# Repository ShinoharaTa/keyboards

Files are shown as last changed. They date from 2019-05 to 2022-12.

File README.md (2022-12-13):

# Shinohara設計キーボード情報

([Click here for the English version of the document.](./LICENSE))

ここには私、Shinoharaの作成したキーボードの情報を記載します。

以下、必要なドキュメント

- [篠原氏の基板設計データ利用規約に関して](./License.md)
- [Amazon 欲しい物リスト](https://www.amazon.co.jp/hz/wishlist/ls/36H4COTLUYA0M?ref_=wl_share)

## BlackMask60 (非売品)

初設計の左右分割 Column Staggardキーボード  
部品点数を削減してシンプルにしつつ耐久性やスイッチ交換可能などのメンテナンス性を確保  
販売はありません。

→後継製品：RURA66

## 素 - Shiro (終売)

2019年の販売開始から2022年まで継続したロングセラー商品
以下でお取り扱いがありました。  



### 販売情報

- [Booth](https://shino3.booth.pm/items/1444895)
- [遊舎工房](https://shop.yushakobo.jp/products/consign_shiro)
- [迷宮商会](https://store.shopping.yahoo.co.jp/meikyuu/gj-kb-201907270001.html)

※現在は終売しました。  
基板のみ販売を継続しています。

### 設計データ

[キーボードの設計データを公開しました。](https://github.com/ShinoharaTa/keyboards/tree/master/Shiro/pcb/Shiro)  
設計データの利用にあたっては、かならず利用規約を読み、同意の上での活用をお願いします。

## 玄 - Kuro

名刺サイズをベースに拡張したキーボード  

- 30%キーボード
- 左右分離式
- 拡張部品で親指対応

## RURA66

BlackMask60ベースに再設計したキーボード

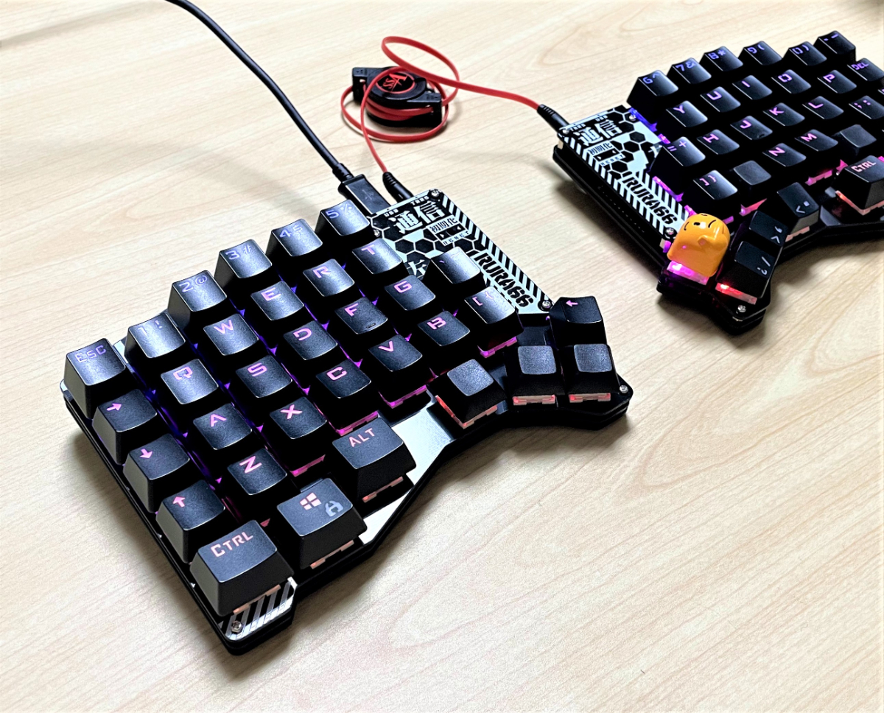
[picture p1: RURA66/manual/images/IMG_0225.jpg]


- 左右分離式
- キーソケットなし
- 価格抑えめ
- Backlight LED（オプション）
- OLED（オプション）

### 販売情報

- [Booth](https://booth.pm/ja/items/2643797)

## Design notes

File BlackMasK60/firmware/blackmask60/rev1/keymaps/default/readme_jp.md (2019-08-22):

# The Default Helix Layout
## 配列

### Qwerty配列

```
 ,-----------------------------------------.             ,-----------------------------------------.
 |   `  |   1  |   2  |   3  |   4  |   5  |             |   6  |   7  |   8  |   9  |   0  | Del  |
 |------+------+------+------+------+------|             |------+------+------+------+------+------|
 | Tab  |   Q  |   W  |   E  |   R  |   T  |             |   Y  |   U  |   I  |   O  |   P  | Bksp |
 |------+------+------+------+------+------|             |------+------+------+------+------+------|
 | Ctrl |   A  |   S  |   D  |   F  |   G  |             |   H  |   J  |   K  |   L  |   ;  |  '   |
 |------+------+------+------+------+------+------+------+------+------+------+------+------+------|
 | Shift|   Z  |   X  |   C  |   V  |   B  |   [  |   ]  |   N  |   M  |   ,  |   .  |   /  |Enter |
 |------+------+------+------+------+------+------+------+------+------+------+------+------+------|
 |Adjust| Esc  | Alt  | GUI  | EISU |Lower |Space |Space |Raise | KANA | Left | Down |  Up  |Right |
 `-------------------------------------------------------------------------------------------------'
```

他の配列(Colemak,Dvorak)は、[readme.md](readme.md) を参照

## コンパイルの仕方

コンパイルは、qmk_firmware のトップディレクトリで行います。

```
$ cd qmk_firmware
```
qmk_firmwareでは各キーボードのコンパイルは、`<キーボード名>:<キーマップ名>`という指定で行います。

```
$ make helix:default
```

キーボードへの書き込みまで同時に行うには下記のように`:avrdude`を付けます。

```
$ make helix:default:avrdude
```

コンパイル結果と中間生成物を消去したい場合は以下のようにします。

```
$ make helix:default:clean
```

## カスタマイズ

Helix キーボードを4行版として製作したり、オプションの OLED をつけたり、
RGB バックライトまたは、RGB Underglow をつけた場合は、
`qmk_firmware/keyboards/helix/rev1/keymaps/default/rules.mk` の以下の部分を編集して機能を有効化してください。

```
# Helix keyboard customize
# you can edit follows 7 Variables
#  jp: 以下の7つの変数を必要に応じて編集します。
HELIX_ROWS = 5              # Helix Rows is 4 or 5
OLED_ENABLE = no            # OLED_ENABLE
LOCAL_GLCDFONT = no         # use each keymaps "helixfont.h" insted of "common/glcdfont.c"
LED_BACK_ENABLE = no        # LED backlight (Enable WS2812 RGB underlight.)
LED_UNDERGLOW_ENABLE = no   # LED underglow (Enable WS2812 RGB underlight.)
LED_ANIMATIONS = yes        # LED animations
IOS_DEVICE_ENABLE = no      # connect to IOS device (iPad,iPhone)

```

## 4行版Helix に対応する

rules.mk の下記の部分を編集して 5 を 4 に変更してください。

```
HELIX_ROWS = 4              # Helix Rows is 4 or 5
```

## RGB バックライトを有効にする

rules.mk の下記の部分を編集して no を yes に変更してください。

```
LED_BACK_ENABLE = yes        # LED backlight (Enable WS2812 RGB underlight.)
```

## RGB Underglow を有効にする

rules.mk の下記の部分を編集して no を yes に変更してください。
```
LED_UNDERGLOW_ENABLE = yes   # LED underglow (Enable WS2812 RGB underlight.)
```

## OLEDを有効にする

rules.mk の下記の部分を編集して no を yes に変更してください。
```
OLED_ENABLE = yes            # OLED_ENABLE
```

## iPad/iPhoneサポートを有効にする。

rules.mk の下記の部分を編集して no を yes に変更してください。
RBG Underglow や RGBバックライトの輝度を抑えて、iPad, iPhone にも接続できるようになります。

```
IOS_DEVICE_ENABLE = no      # connect to IOS device (iPad,iPhone)
```

## リンク

* さらに詳細は、[こちら helix/Doc/firmware_jp.md](https://github.com/MakotoKurauchi/helix/blob/master/Doc/firmware_jp.md)をご覧ください。
* [Helix top](https://github.com/MakotoKurauchi/helix)

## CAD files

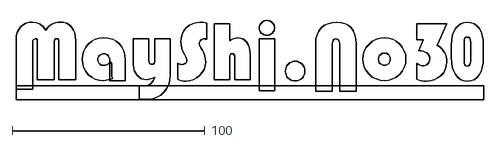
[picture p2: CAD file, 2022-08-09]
Shiro/pcb/Shiro/design/logo_confirm.dxf
242.5 x 41.0

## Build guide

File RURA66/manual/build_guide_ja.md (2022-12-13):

# 左右分割 60% キーボード「RURA66」ビルドガイド

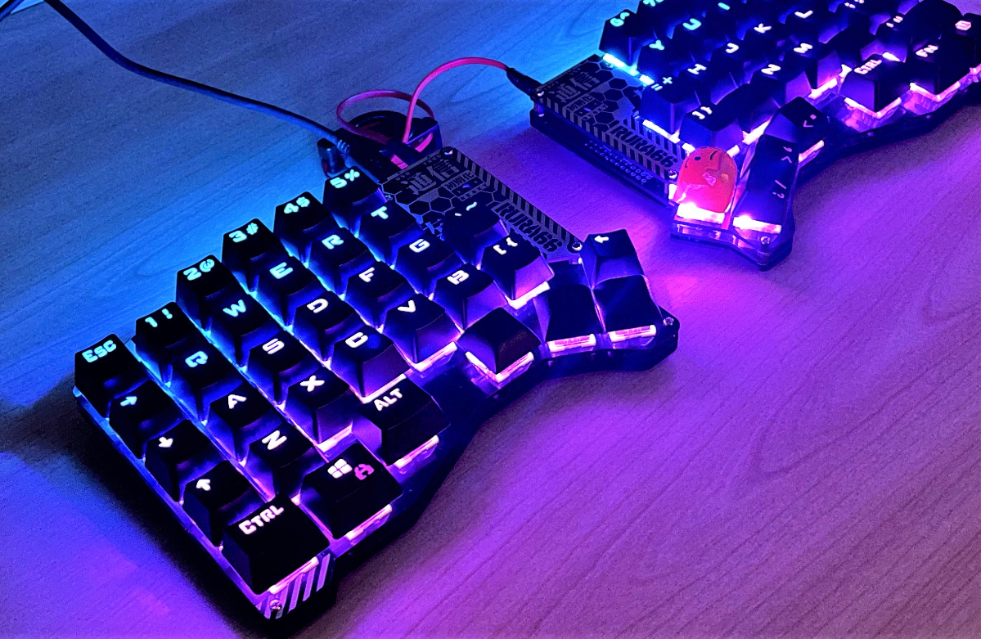
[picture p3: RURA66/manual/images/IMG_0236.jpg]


## はじめに

このキーボードは66キーの左右分割型キーボードです。  
部品点数を削り、最小構成は基本要素のみに限定しているため、左右分割ColumnStaggerdを手軽に試してみたい方も利用できます

## お問合せ先

製品に関しまして、ご不明点や不備、また部品の不足がございましたら、以下フォームよりご連絡ください。
※お問い合わせからお返事まで少々お時間を頂く場合がございます。

https://forms.gle/LfstzLrk8dojknbf6

不足部品に関しましては、当方よりご連絡いただいた住所へ送付させていただきます。

## 部品リスト

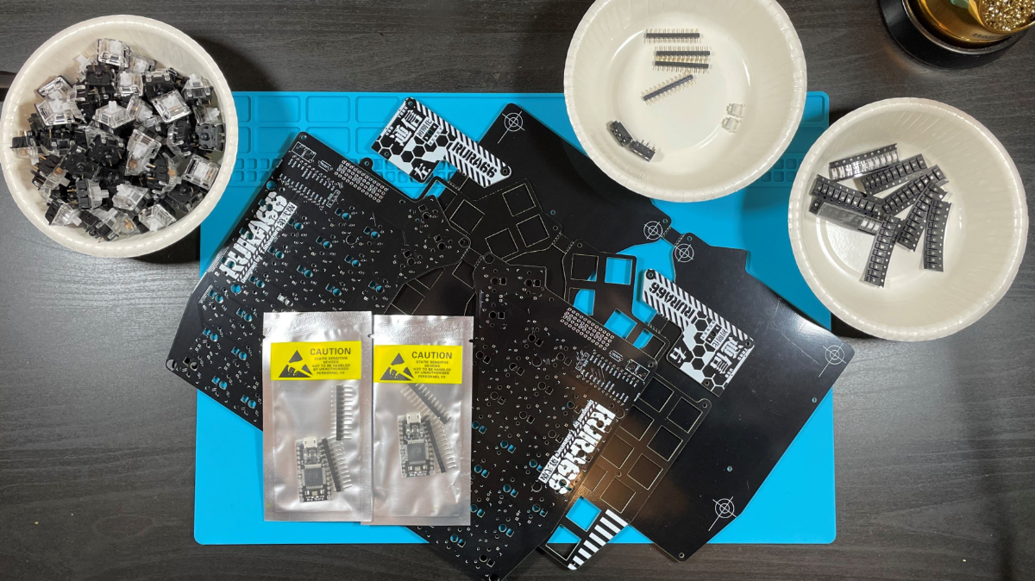
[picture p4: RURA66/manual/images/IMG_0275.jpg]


**キット同梱品**

- PCB x1
- トッププレート x1
- ボトムプレート x1
- チップダイオード x66（予備あり）
- リセットスイッチ x2
- TRRSジャック x2
- ProMicro x2
- コンスルーピンヘッダ x4
- ネジ 4mm x40（予備あり）
- スペーサー 7mm x20（予備あり）

**ご自身で買い揃えていただくもの**
（全て遊舎工房で入手できます）

- Cherry MX スイッチ及び互換スイッチ x66
- キーキャップセット（1uのみ。不足は適宜買い足してください）
- RGB_LED YS-SK6812MINI-E x66（オプション）
- USBケーブル
- TRRSケーブル(3極以上)

## 必要な工具



- ハンダゴテ（温度調節可能なもの推奨）
- ピンセット
- ラジオペンチ
- プラスドライバー（2mm）
- 棒ヤスリ

## 作り方の手順

以下、組み立て手順の図は片手側でおこないます。  
RURA66の基板設計は左右専用設計であるため、実装面に沿って作っていただくことが可能です。

### 基板の分離と加工

まずは基板を点線に沿って切り落とします。  
ラジオペンチで掴んで慎重に追ってください。



点線のバリをヤスリがけして整えます。



お好みで、側面を黒の油性ペンで塗るといい感じになります。

### バックライトLEDの取り付け（オプション）

**※この項目はバックライトLEDをオプションで購入し、光らせたい人むけの情報となります。**

（初期ロットのみ）LEDの枠が小さいため、下記の図のようにヤスリで穴を広げます。  
おすすめは100円ショップ等で取り扱いのある三角/四角のダイヤモンドヤスリを使用します。



以下の図のように、LEDの向きをマークにあわせて配置します。全部、向きは一緒になります。  
はんだ付けのときは、270度似設定してください。長時間コテを当てるとLEDが星になります。

一つだけハンダを乗せたら、再度溶かして素早くピンセットで向きを変えます。



なるべく、一つのLEDに熱が入りすぎないように、複数を並行にはんだ付けしていきます。  
はんだ付け完了後、動作確認のため先にProMicroの取り付けと、ライトの点灯チェックを行ってください



### ダイオードの取り付け

ダイオードのパッドに、片側ずつ予備ハンダをします。

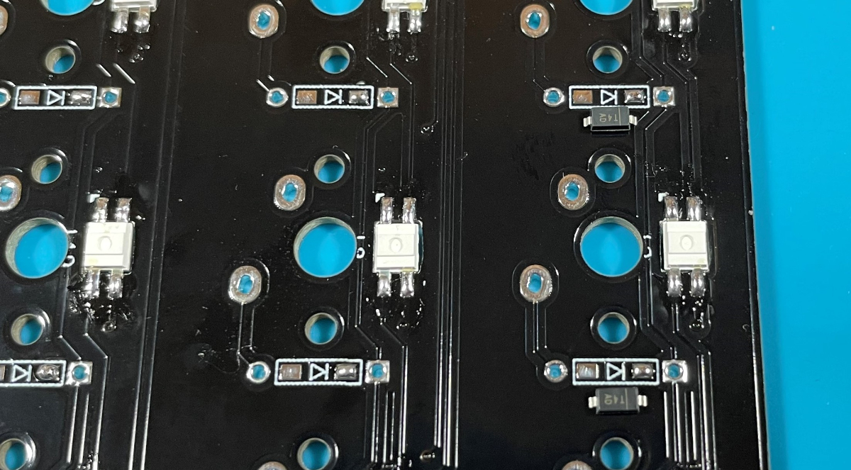
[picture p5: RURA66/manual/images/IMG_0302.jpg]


ダイオードの向きを揃えて、ピンセットではんだ付けしていきます。  
**※極性注意・・・！！**

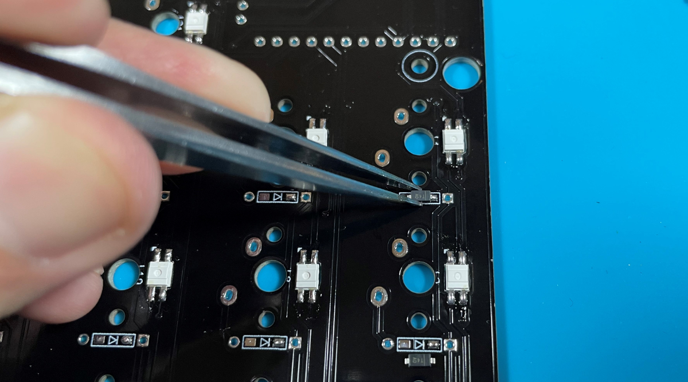
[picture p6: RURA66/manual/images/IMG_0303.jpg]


全部で33個、同じ向きに配置します。

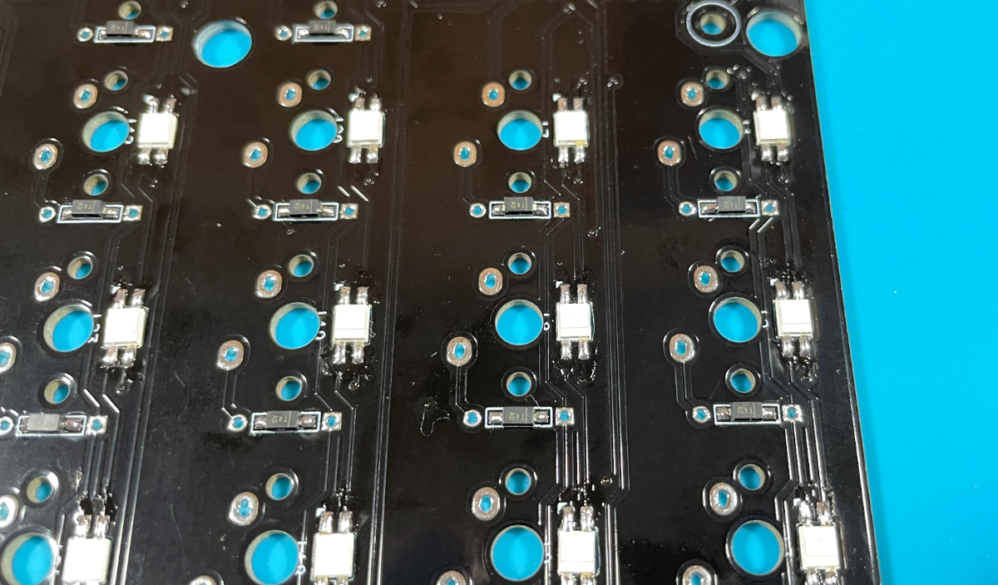
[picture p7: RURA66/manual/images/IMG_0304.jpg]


### TRRSジャックとリセットスイッチの取り付け

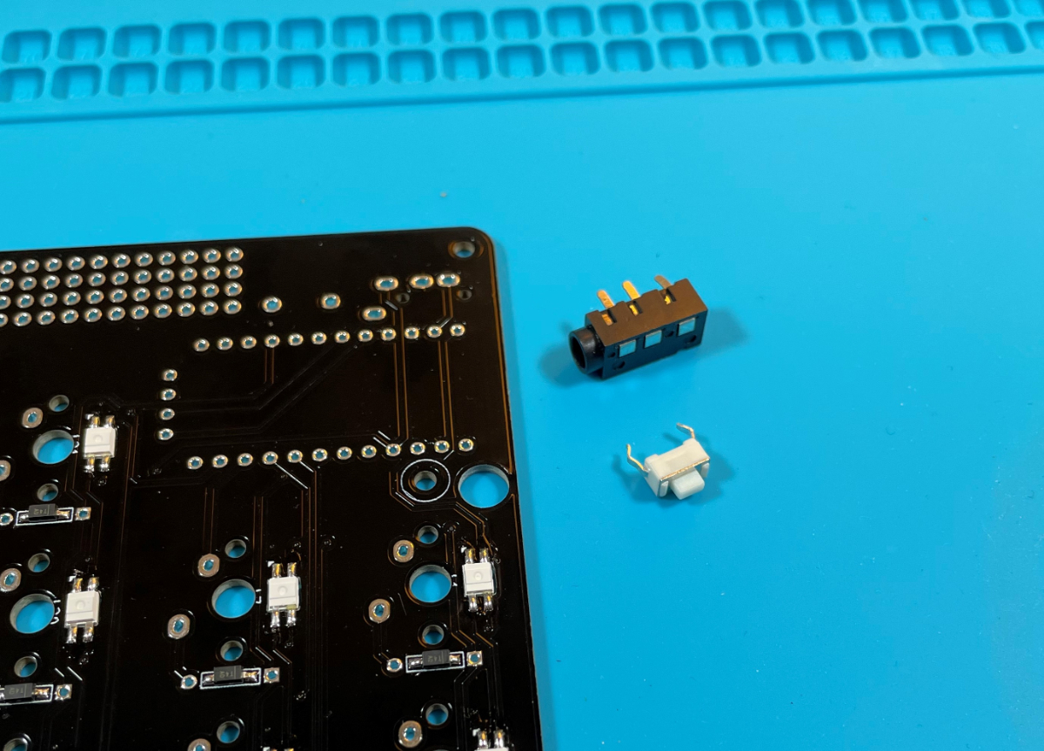
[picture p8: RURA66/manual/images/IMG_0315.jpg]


TRRSジャックから先に取り付けを行います。  
どちらも同じ面から入れ、裏からはんだ付けします。

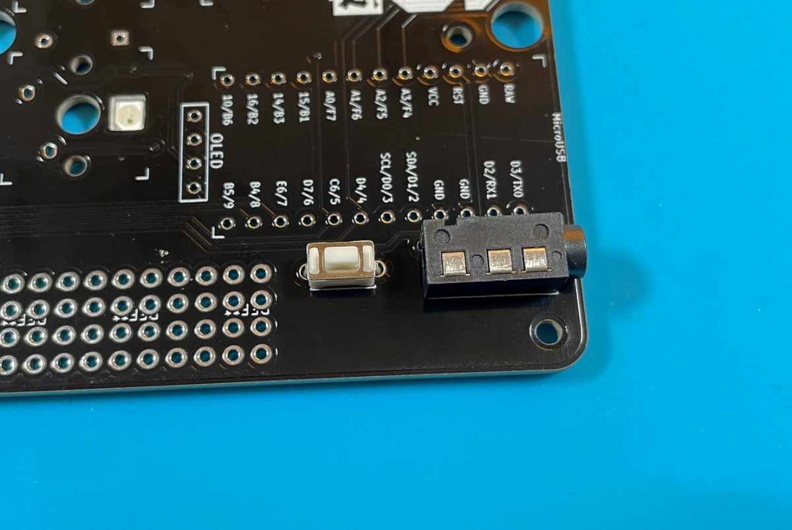
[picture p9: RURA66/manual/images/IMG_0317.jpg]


### スイッチの取り付け

※初期ロットはGateron等の5ピンに対応しておりません。  
5ピンのスイッチを使用する場合は、足を切る必要があります。

メカニカルスイッチをはんだ付けしていきます。  
まずは、トッププレートにスイッチをはめていきます。

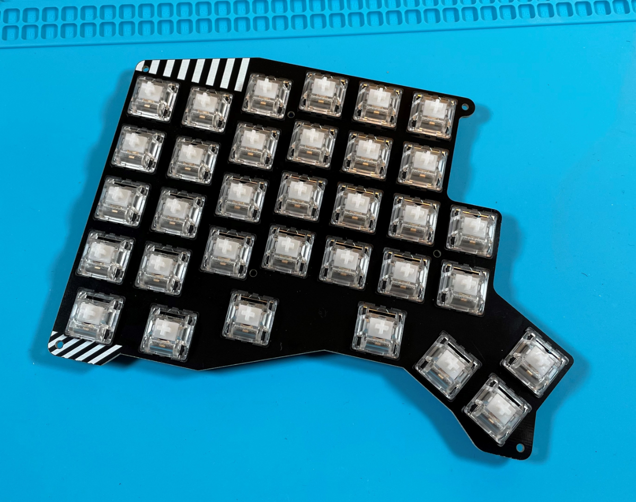
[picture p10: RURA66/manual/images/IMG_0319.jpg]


33個はめます。向きはおなじ方向にまとめてください。  
ピンが折れ曲がっている場合は、手でまっすぐに伸ばしてください。

浮かないように、まず対角をはんだ付けします。  
その後、全体的に浮かないように一つずつ確認しながらはんだ付けをしていきます。

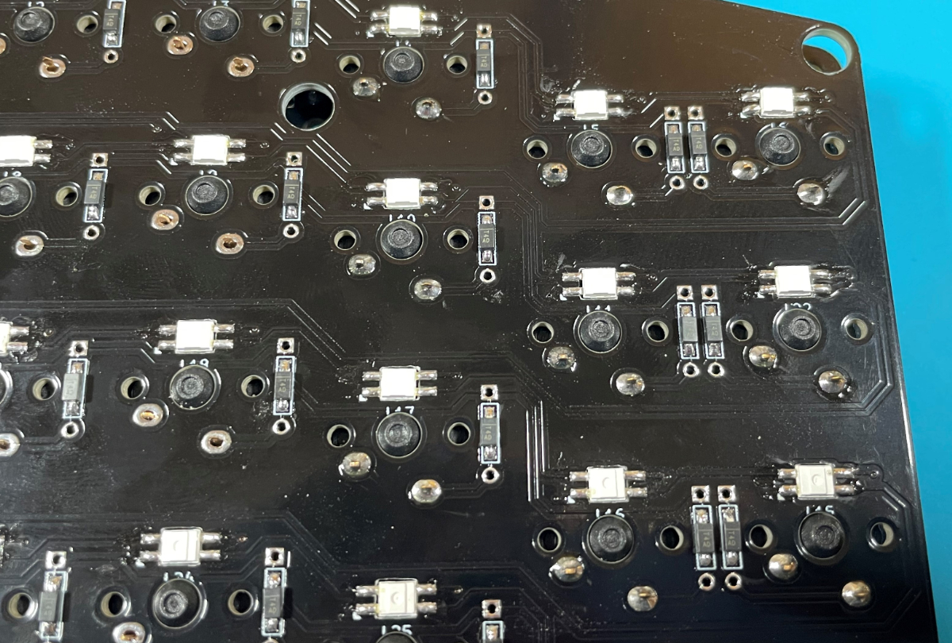
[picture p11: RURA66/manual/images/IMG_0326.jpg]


### ProMicroの取り付け

付属のピンヘッダは使いません。コンスルーピンヘッダを使用します。

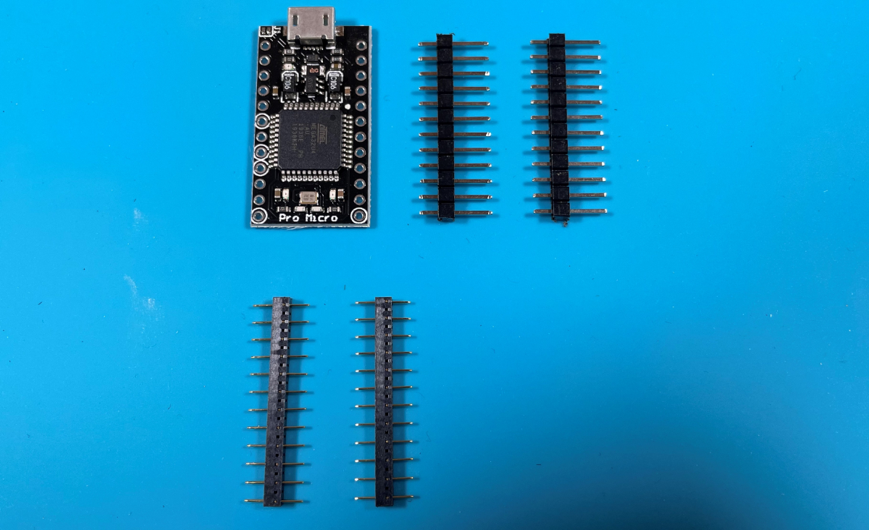
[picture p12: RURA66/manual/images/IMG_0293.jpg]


向きを揃えてコンスルーピンヘッダを指します。

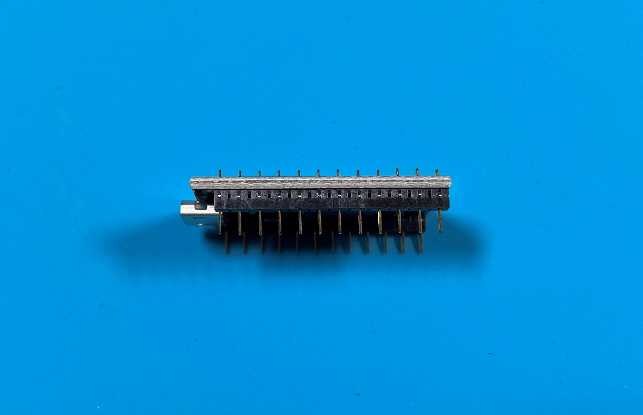
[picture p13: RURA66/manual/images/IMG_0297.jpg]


ProMicroを載せます。

その後、以下の写真のProMicro側のみ（写真の面のみ）をはんだ付けします。

※メインPCB側は、はんだ付け不要です。

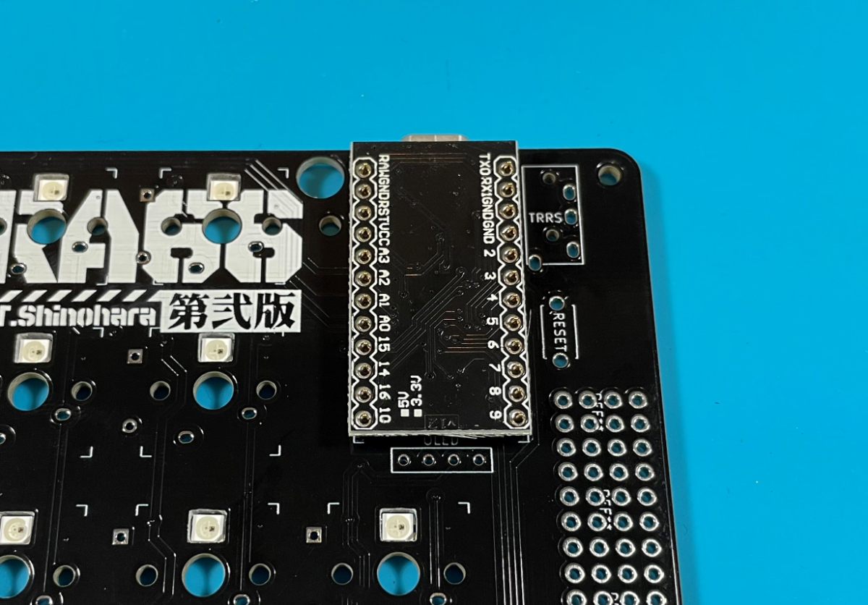
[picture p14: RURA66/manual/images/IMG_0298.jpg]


### ボトムプレート、カバープレートの固定

あまり力を入れすぎずに、ラジオペンチとドライバーを使用して固定してください。  
トッププレート、ボトムプレートをスペーサーと連結し、ネジで留めていきます。

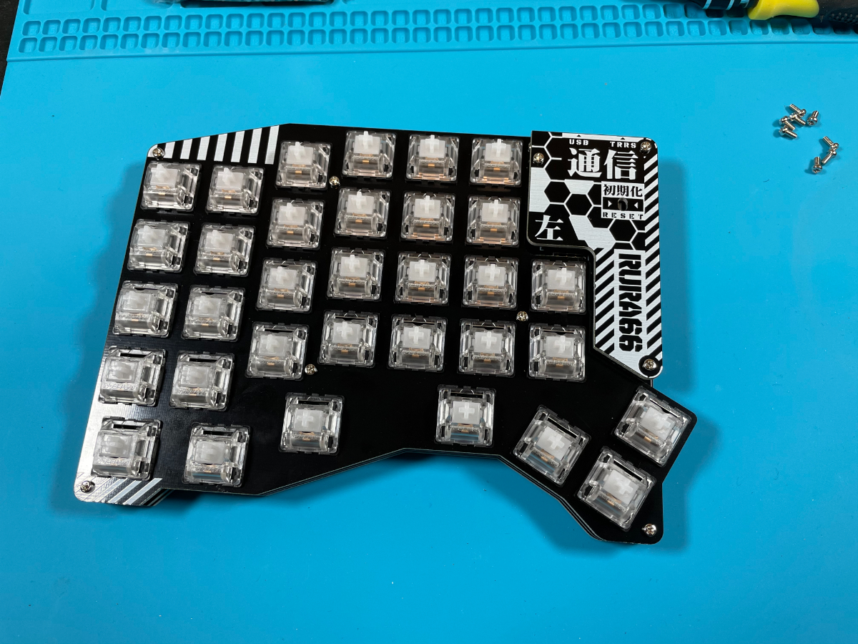
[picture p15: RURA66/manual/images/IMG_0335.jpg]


### 完成に向けて

ゴム足を4隅につけます。  
お好みのキーキャップを取り付けて完成です。



## QMK Firmwareの書き込み

このキーボードは[QMK firmware](https://github.com/qmk/qmk_firmware/)に対応します。  
書き込み手順はQMK Firmwareの使用手順・書き込み手順は公式のドキュメントを参考にしてください

QMKコマンドの使用

```
qmk flash -kb rura66 -km default
```

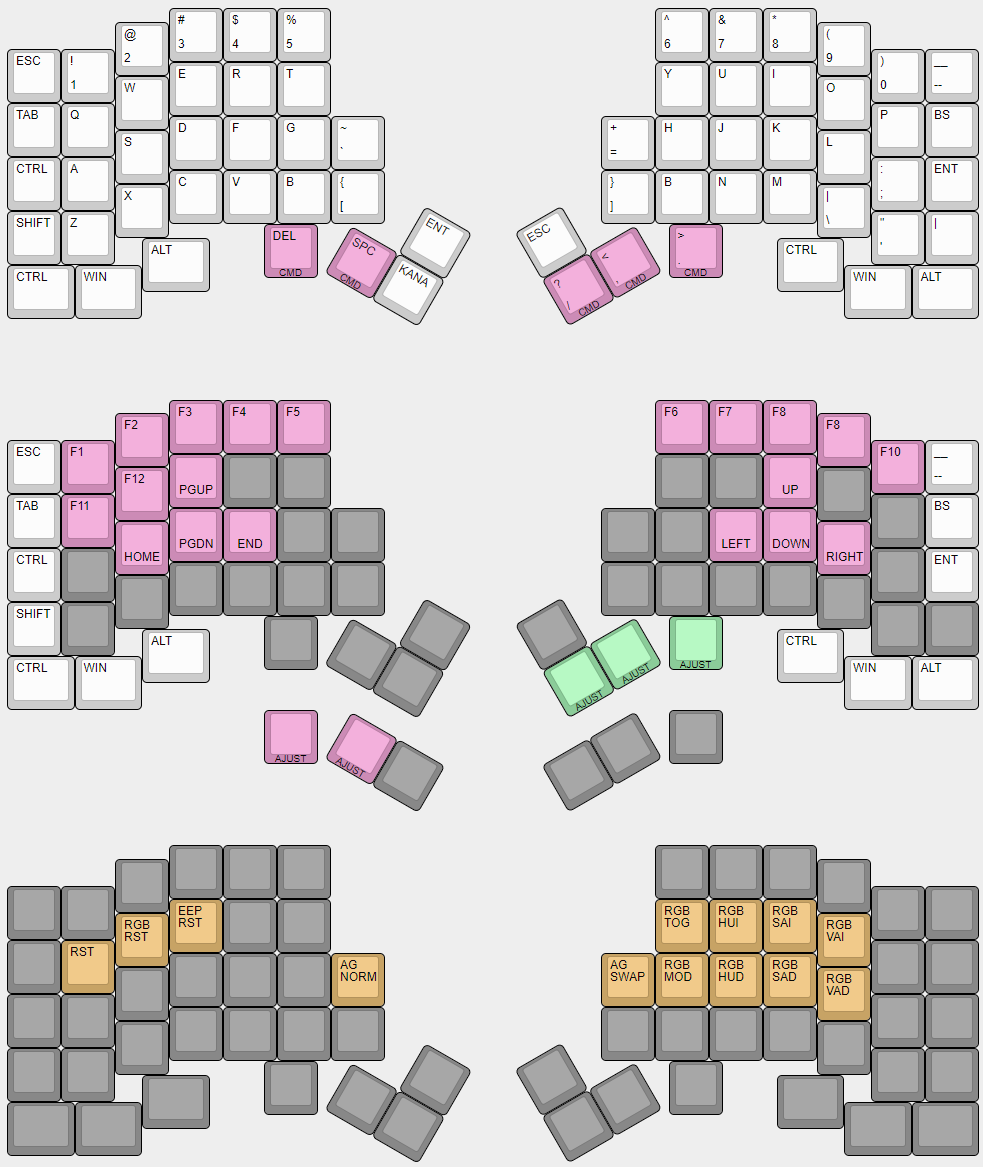
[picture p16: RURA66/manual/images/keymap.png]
keymap


キーマップの変更については`keyboards/rura66/keymap/default`をコピーして、お好きなフォルダ名で保存し、変更を行います。

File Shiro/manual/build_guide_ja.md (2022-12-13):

# マクロキーボード「素 - Shiro」ビルドガイド

2022/8/1より、素-Shiro はオープンソースPCBになりました。

素 - Shiro オープンソースPCBの説明は[こちら](./build_guide_open_source_pcb_ja.md)

素 - Shiro Classicのビルドガイドは[こちら](./build_guide_classic_ja.md)

## はじめに



このキーボードは15キーの縦型キーパッドです。

部品点数を削ったので組み立て難易度は比較的カンタンになっています。

## お問合せ先

製品に関しまして、ご不明点や不備、また部品の不足がございましたら、以下フォームよりご連絡ください。
※お問い合わせからお返事まで少々お時間を頂く場合がございます。

https://forms.gle/LfstzLrk8dojknbf6

不足部品に関しましては、当方よりご連絡いただいた住所へ送付させていただきます。

## 部品リスト

**キット同梱品**



- PCB x1
- トッププレート x1
- ボトムプレート x1
- チップダイオード x15
- リセットスイッチ x1
- ネジ 3mm x6
- ネジ 5mm x4
- スペーサー 5mm x6

**ご自身で買い揃えていただくもの**
（全て遊舎工房で入手できます）



- ProMicro（コンスルーピンヘッダ同梱品）
- Kailh Choc（ロープロスイッチ）x15
- ロープロ対応キーキャップ x15

## 作り方の手順

私が組んだときの手順になりますが、この手順に沿って行えば一応ミスなく組めています。
部品の破損や取付ミスを防ぐためにも、手順は一つ一つ確認しながら進めてください。

### ダイオードの取り付け

ダイオードのパッドに、片側ずつ予備ハンダをします。



ダイオードの向きを揃えて、ピンセットではんだ付けしていきます。
※極性注意・・・！！



全部で15個、同じ向きに配置します。

### リセットスイッチの取り付け

リセットスイッチはこの面から差し込みます



はんだ付けは、こっちの面からおこないます。



### スイッチの取り付け

いよいよメカニカルスイッチをはんだ付けしていきます。
まずは、トッププレートにスイッチをはめていきます。



とりあえず、13個はめます。
折れ曲がっている場合は、手でまっすぐに伸ばしてください。



13箇所入っていることを確認します



浮かないように、まず対角をはんだ付けします。
その後、全体的に浮かないように一つずつ確認しながらはんだ付けをしていきます。

トッププレートに固定されていないスイッチ2個については、そのまま穴に差し込み、同様にはんだ付けします。  
この際、固定の角度のズレ、曲がりにご注意ください。



### ProMicroの取り付け

付属のピンヘッダは使いません。コンスルーピンヘッダを使用します。



向きを揃えてコンスルーピンヘッダを指します。



ProMicroを載せます。

向きは、実装面がオモテに来るように載せてください。  
その後、以下の写真の様にProMicro側のみ（写真の面のみ）をはんだ付けします。

※ShiroのメインPCB側は、はんだ付け不要です。



### カバーの取り付け

カバーをネジ止めしていきます。
短い方のネジ6本、スペーサー6本、ボトムプレートを用意してください。



上記のように、6箇所をネジ止めします。



トッププレートとドッキングします。
4箇所をあわせて、長い方のネジでとめます。



### 完成に向けて

ゴム足を4隅につけます。





お好みのキーキャップを取り付けて完成です。





## QMK Firmwareの書き込み

このキーボードは[QMK firmware](https://github.com/qmk/qmk_firmware/)に対応します。  
書き込み手順はQMK Firmwareの使用手順・書き込み手順は公式のドキュメントを参考にしてください

QMKコマンドの使用

```
qmk flash -kb shiro -km default
```

keymap

キーマップの変更については`keyboards/shiro/keymap/default`をコピーして、お好きなフォルダ名で保存し、変更を行います。

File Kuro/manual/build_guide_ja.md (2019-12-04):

# 分割キーボードキット「玄 - Kuro」ビルドガイド

## はじめに

メイン画像

このキーボードは片側17キー、両手最大34キーの左右分割キーボードです。

組み立てには一部部品の加工、配線などを含みます。また、LEDの実装や、基盤のバリ落としなどが必要となります。

**※注意事項**

- 先行販売分は、ProMicroを使用するスルーホールが一部埋まっています。ピンセットなどで塗膜を落としてください。
- この記事はまだ執筆中です。ご自身が過去にキーボード組み立てた経験をもとに制作してください。
- この記事は深夜４時に書いています。説明用画像が全然足りていません。

## 部品リスト

**キット同梱品**

※画像

- PCB x2
- ボトムプレート x2
- 拡張プレート x2
- チップダイオード x30
- リセットスイッチ x2
- TRRSジャック x2
- ネジ 3mm x20
- ネジ 5mm x8
- スペーサー 5mm x16
- 配線 x6 (3色 2本ずつ）
- 絶縁テープ

**ご自身で買い揃えていただくもの**
(全て遊舎工房で入手できます)

- ProMicro（コンスルーピンヘッダ同梱品）x2
- Kailh Choc(ロープロスイッチ) x34
- ロープロ対応キーキャップ x34
- SK6812MINI LED x30

## 作り方の手順

私が組んだときの手順になりますが、この手順に沿って行えば一応ミスなく組めています。
部品の破損や取付ミスを防ぐためにも、手順は一つ一つ確認しながら進めてください。

作例は左手用です。拡張プレートの取付までは、左右による差異はありません。

### ダイオードの取り付け

ダイオードのパッドに、片側ずつ予備ハンダをします。

※画像

ダイオードの向きを揃えて、ピンセットではんだ付けしていきます。
※極性注意・・・！！

※画像

全部で15個、同じ向きに配置します。

### LEDのはんだ付け（オプション）

この項目はLEDを実装する場合の手順です。無くても構いません。

**LEDは熱に弱いので、ハンダゴテの温度は下げてください。**

※記事を書く。画像いれる。

### リセットスイッチの取り付け

リセットスイッチはこの面から差し込みます

※画像

はんだ付けは、こっちの部品面からおこないます。

※画像

ここでLEDの動作確認を一度行うことをおすすめします。
先に、ProMicroの準備と、QMKファームウェアを書き込みます。

### TRRSジャックの取り付け

TRRSを取り付けます。

※画像

反対面のスイッチと干渉するので、足を短く切ります。（短すぎないように注意）

※画像

ハンダが表面に盛られない程度にはんだ付けします。

※画像

### スイッチの取り付け

いよいよメカニカルスイッチをはんだ付けしていきます。
スイッチの足が折れ曲がっている場合は、手でまっすぐに伸ばしてください。

以下の丸で示した位置は加工が必要です。

ProMicroと重なる位置、一番外側の足は、スイッチと同じ高さになるよう調整してください。

TRRSジャックと重なる位置、プラスチックの足を基板の高さまで切り落としてください。

### ProMicroの取り付け

付属のピンヘッダは使いません。コンスルーピンヘッダを使用します。

![] (https://cdn.discordapp.com/attachments/536423734144401422/597460617997189120/20190707_032439.jpg)

向きを揃えてコンスルーピンヘッダを指します。



ボトムプレート付属の、絶縁テープをUSB部分に張ります。

※画像

ProMicroを載せます。
その後、以下の写真の様にProMicro側のみ（写真の面のみ）をはんだ付けします。
**メインPCB側は、はんだ付け不要です。**

※画像

### 拡張プレート側の加工

へし折ります。

削ります。（ヤスリがあると良し。）

スイッチをはんだ付けします。
**向き注意！！**

### 配線

線の長さをある程度揃えます。キットにより長さは異なります。

※画像

2mmほど被覆をはがし、呼びハンダします。

※画像

基板側にも呼びハンダし、１～３まで、順にはんだ付けします。

※画像

拡張プレート側も同様にはんだ付けします。

※画像

### カバーのネジ止め取り付け

ボトムプレート側から固定していきます。

基板を２枚挟むときは5mmのネジを使用します。
それ以外の箇所は4mmのネジを使います。

※画像

拡張基板側に4mmのネジとスペーサーを固定します。

※画像

メインPCBと4mmのネジで止めます。画像の４箇所です。

※画像

拡張基板の位置決めをして、固定します。

※画像

なお、拡張基板は一番寝かせた状態のとき、はみ出る部分は折って使うことが可能です。

※画像

### 完成に向けて

ゴム足を4隅につけます。

※画像

お好みのキーキャップを取り付けて完成です。

※画像

## QMK Firmwareの書き込み

※後日、公開します。

下記ページよりQMKファームウェアをダウンロードします。

https://github.com/ShinoharaTa/qmk_firmware/tree/kuro

右上、"Clone or download"ボタンより。

そしてダウンロードしたZIPファイルはお好きなところで展開します。
フォルダ階層はなるべく浅いほうがいいです。

gitに慣れている方はクローンしていただいても構いません。

環境構築については、こちら[Helixのビルドマニュアル](https://github.com/MakotoKurauchi/helix/blob/master/Doc/firmware_jp.md)が詳しく解説されています。

**ビルドと書き込み**

```
make kuro:defualt:avrdude
```

これを実行すると本番用のキーマップを書き込めます。
デフォルトでは以下のようになっています。

※キーマップ画像

キーマップの変更については`keyboards/kuro/rev2/keymap/default`をコピーして、お好きなフォルダ名で保存し、変更を行います。

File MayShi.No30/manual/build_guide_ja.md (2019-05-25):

# MayShi.No30 ビルドガイド

## はじめに

このキーボードはmeishi展に出品したキーボードで、基板のサイズは91mm x 55mmのキーボードになります。
左右のスプリットに対応し、ケースで縦方向に拡張すると、最大34キーのキーボードになります。



## 部品リスト

**キット同梱品**

- PCB x1
- トッププレート x1
- ボトムプレート x1

**ご自身で買い揃えていただくもの**
(全て遊舎工房で入手できます)

- ProMicro
- コンスルーピンヘッダ x2
- 面実装ダイオード x15
- Kailh Choc(ロープロスイッチ) x15
- ロープロ対応キーキャップ x15
- LED
- タクトスイッチ
- 3.5mm ステレオケーブル（4極を推奨しています）
- ネジ(5mm, 4mm)
- スペーサー(3mm)x6

## 作り方の手順

1. 瞑想をして集中力を高めます。
1. 基板を片手に組み立てている自分の姿を妄想します。
1. 部屋の片付け、掃除をして雑念を排除します
1. LEDの穴が小さいです。100円ショップに売っているダイヤモンドヤスリで0.2mm〜0.5mmぐらいガリガリ削ります
1. LEDを実装します。
1. ダイオードを実装します。
1. 目が疲れてくるので、休憩をはさみます。
1. TRRSジャックはそのまま入りません。位置合わせのピンを落とします。
1. TRRSジャックがLEDのはんだと干渉します。当たるところをヤスリで落とします。
1. TRRSジャックをはんだ付け前に、PCBの高さで足を切ります。
1. TRRSジャックをはんだ付けします。
1. タクトスイッチをはんだ付けします。
1. ProMicroはいつものように準備します。
1. キースイッチをアクリルにはめていきます。
1. キースイッチをはんだ付けします。ProMicroの真下のは、スイッチの位置決めのピン足がUSBと干渉するので切り落とします。
1. 喉が渇く時間になるのでコカ・コーラを飲みます。
1. LEDは配線不良で途中からつきません。そのうち写真上げます。
1. ケースとカバーをネジどめして組み立てます。ProMicroのとこのネジは応力がかかって破損を防ぐためのもの。ボトムプレートのみに止めます

## Firmware を焼く

QMK Firmwareで、とりあえずHelixのやつ焼けば動きます。
動くものは、出次第自分のTwitterで告知します。もう少々お待ちください。

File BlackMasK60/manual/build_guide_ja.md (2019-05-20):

# BlackMasK60ビルドガイド

## はじめに

このキーボードはキー数がおおよそ60％のキーボードとなります。
キー数は最大70個まで対応で、最小では58個ぐらいになります。

## 部品リスト

**キット同梱品**

- PCB x2
- トッププレート x2
- ボトムプレート x2
- タクトスイッチ x2
- スペーサー 7mm x18
- ネジ 4mm x36
- TRRSジャック x2
- タクトスイッチ x2

**ご自身で買い揃えていただくもの**
(全て遊舎工房で入手できます)

- ProMicro x2
- コンスルーピンヘッダ x4
- キースイッチ（Cherry MX互換） x70
- キーキャップ（Cherry MX互換） x70
- ソケット（Cherry MX用） x70  
とりあえず動くのは70個です。配列を自由に変える場合は90個が理想です。
- ダイオード（SMDも可） x70
- 3.5mm ステレオケーブル（4極を推奨しています）

## 作り方の手順

必ずこの手順に従って組み立てを進めてください。
また、はんだ付けに自身のない方はリード部品が多めのCherry MX互換のものを選択されることを推奨します。

### ダイオードの実装

リードダイオードのはんだ付け
SMDダイオードのはんだ付け

基盤の向き、実装方向
文章は以前のQiita参考

### ソケットの実装

### TRRSジャックの実装

### ProMicroの取り付け

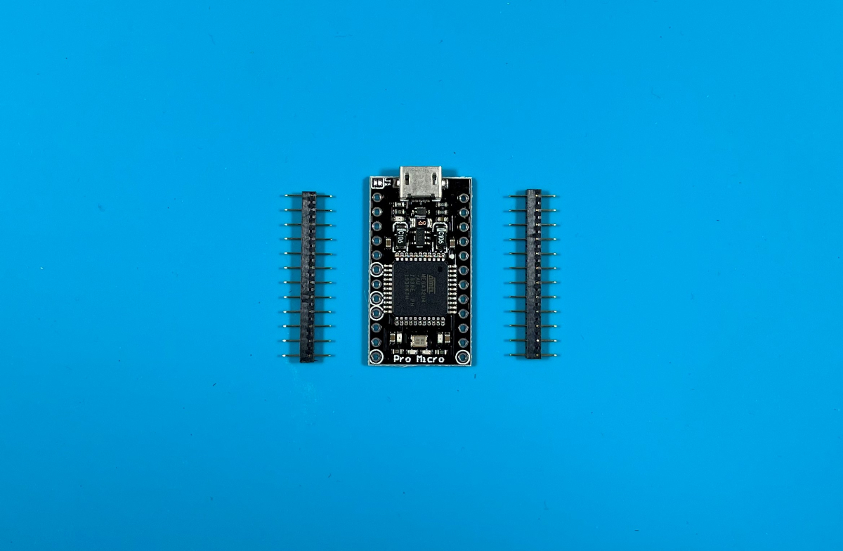
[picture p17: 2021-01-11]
RURA66/manual/images/IMG_0294.jpg

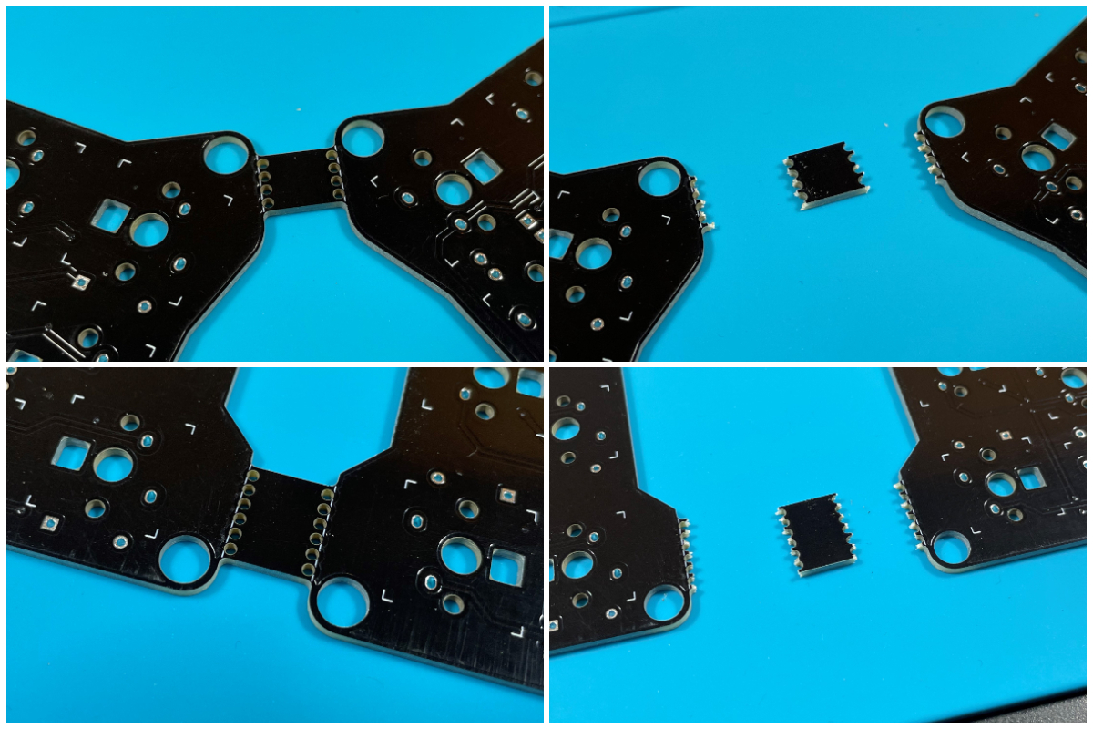
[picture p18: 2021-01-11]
RURA66/manual/images/FotoJet.jpg

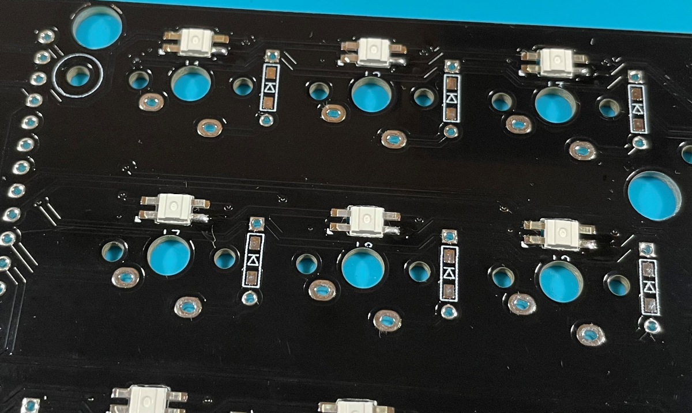
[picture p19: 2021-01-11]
RURA66/manual/images/IMG_0290.jpg

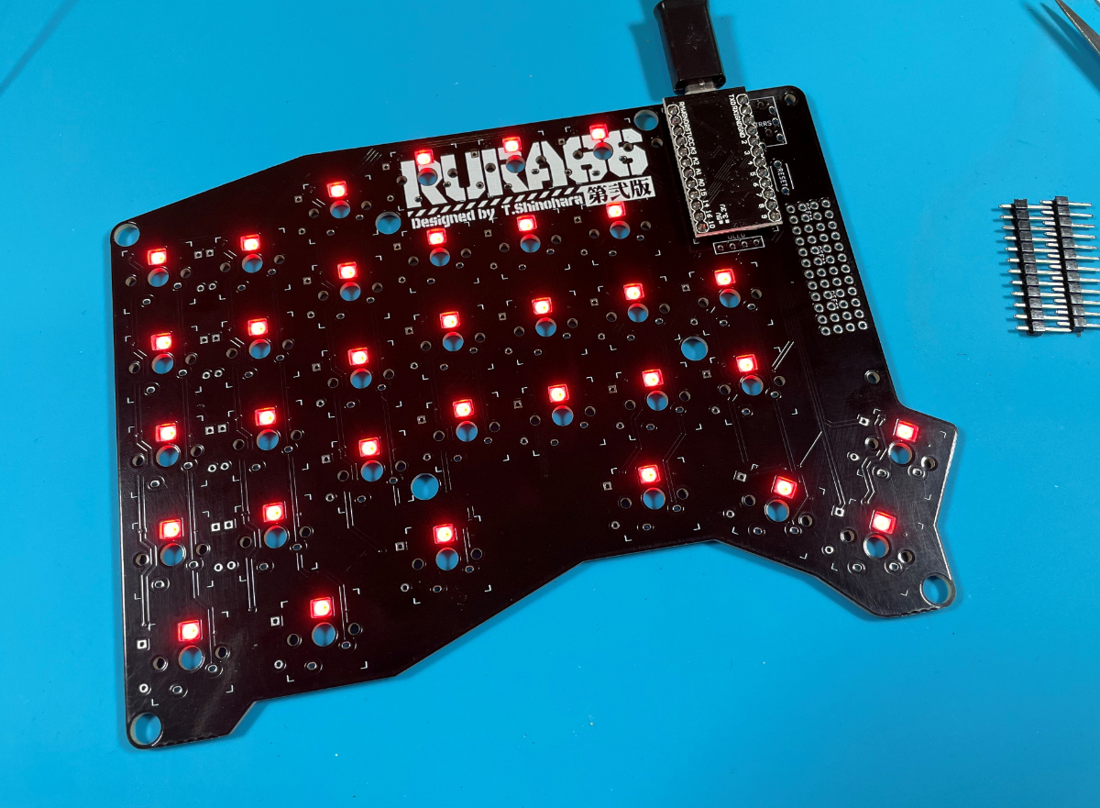
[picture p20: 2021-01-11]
RURA66/manual/images/IMG_0299.jpg

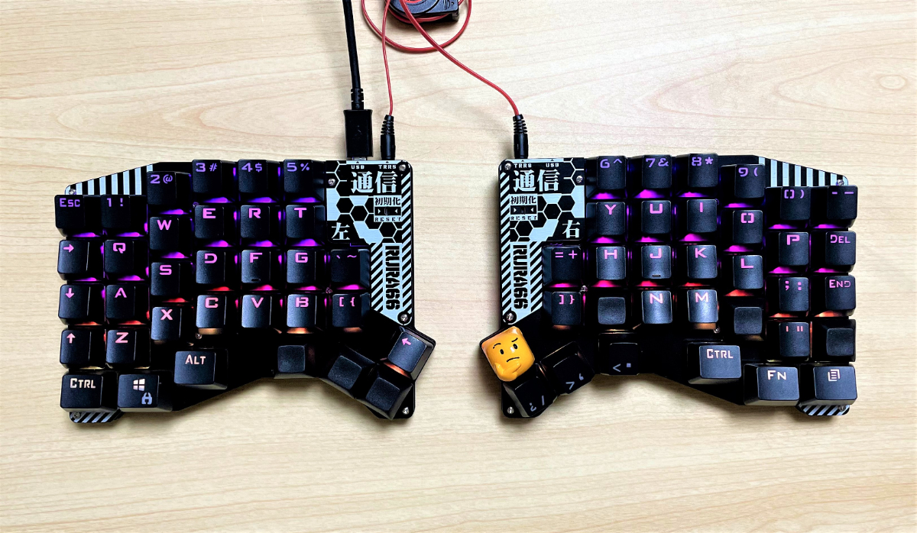
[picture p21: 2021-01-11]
RURA66/manual/images/IMG_0213.jpg

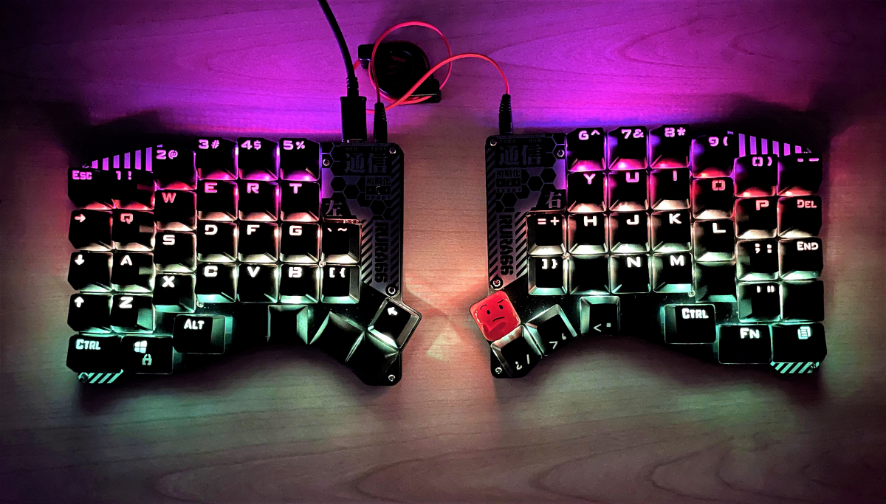
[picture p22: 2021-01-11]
RURA66/manual/images/IMG_0241.jpg

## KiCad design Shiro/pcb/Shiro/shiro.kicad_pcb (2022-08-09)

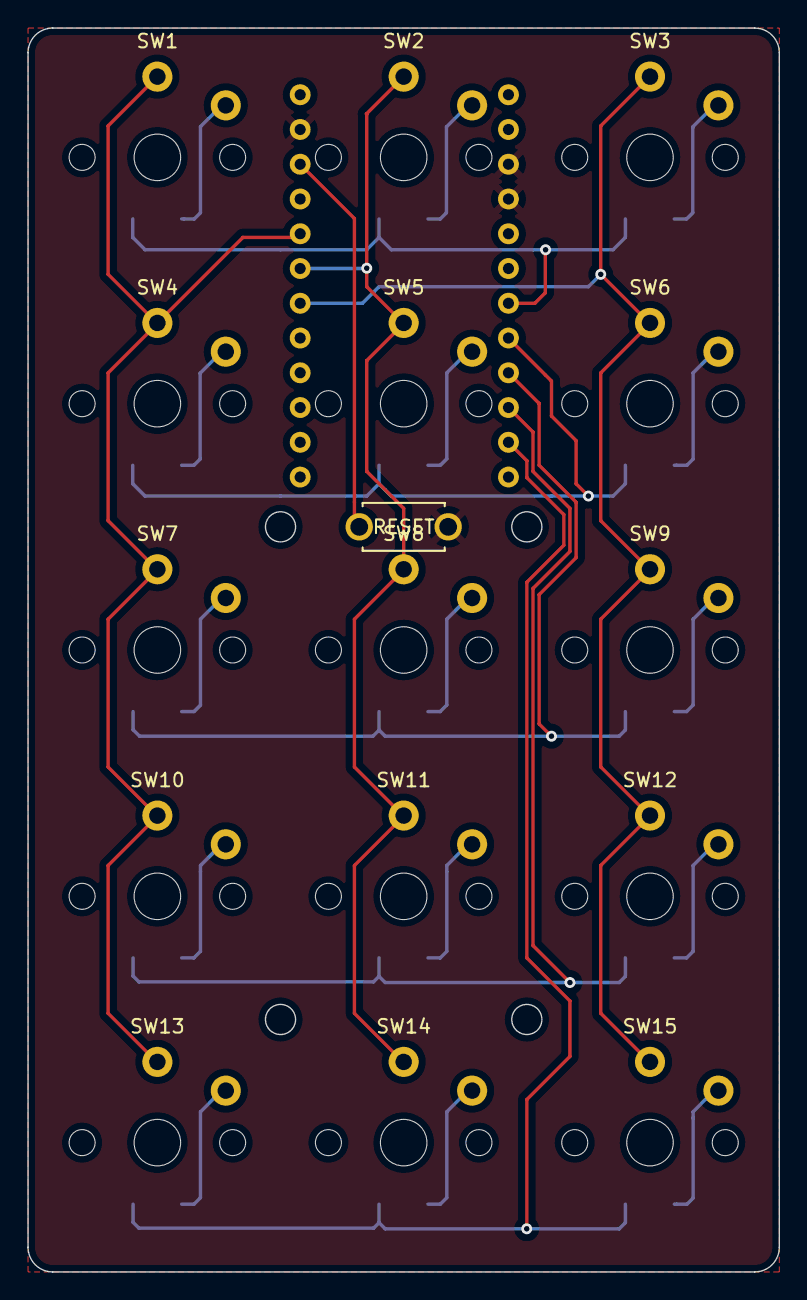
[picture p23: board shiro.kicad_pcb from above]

Board: 2 copper layers, 54.9 x 90.9 mm, 32 parts (0 on the bottom side), 25 nets.

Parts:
D1, D2, D3, D4, D5, D6, D7, D8, D9, D10, D11, D12, D13, D14, D15: D; D3_SMD_1side
SW1, SW2, SW3, SW4, SW5, SW6, SW7, SW8, SW9, SW10, SW11, SW12, SW13, SW14, SW15: SW_PUSH; SW_kailh_pg1350_1u
SW_RST1: SW_PUSH; ResetSW
U1: ProMicro; ProMicro_v2_1side_Rev

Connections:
GND: SW_RST1.2, U1.3, U1.4, U1.23
unnamed: D1.2, SW1.2
unnamed: D2.2, SW2.2
unnamed: D3.2, SW3.2
unnamed: D4.2, SW4.2
unnamed: D5.2, SW5.2
unnamed: D6.2, SW6.2
unnamed: D7.2, SW7.2
unnamed: D8.2, SW8.2
unnamed: D9.2, SW9.2
unnamed: D10.2, SW10.2
unnamed: D11.2, SW11.2
unnamed: D12.2, SW12.2
unnamed: D13.2, SW13.2
unnamed: D14.2, SW14.2
unnamed: D15.2, SW15.2
Reset: SW_RST1.1, U1.22
col0: SW1.1, SW4.1, SW7.1, SW10.1, SW13.1, U1.20
col1: SW2.1, SW5.1, SW8.1, SW11.1, SW14.1, U1.19
col2: SW3.1, SW6.1, SW9.1, SW12.1, SW15.1, U1.18
row0: D1.1, D2.1, D3.1, U1.7
row1: D4.1, D5.1, D6.1, U1.8
row2: D7.1, D8.1, D9.1, U1.9
row3: D10.1, D11.1, D12.1, U1.10
row4: D13.1, D14.1, D15.1, U1.11

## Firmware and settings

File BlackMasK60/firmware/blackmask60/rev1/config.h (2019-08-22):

/*
Copyright 2012 Jun Wako <wakojun@gmail.com>
Copyright 2015 Jack Humbert

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
You should have received a copy of the GNU General Public License
along with this program.  If not, see <http://www.gnu.org/licenses/>.
*/

#ifndef REV1_CONFIG_H
#define REV1_CONFIG_H

/* USB Device descriptor parameter */
#define VENDOR_ID       0xFEED
#define PRODUCT_ID      0x3060
#define DEVICE_VER      0x0001
#define MANUFACTURER    ShinoharaTa
#define PRODUCT         BlackMask60 Beta
#define DESCRIPTION     A split keyboard for the cheap makers


#define PREVENT_STUCK_MODIFIERS
#define TAPPING_FORCE_HOLD
#define TAPPING_TERM 500

/* Use I2C or Serial */
#define USE_I2C
#define USE_SERIAL
//#define USE_MATRIX_I2C

/* Select hand configuration */
#define MASTER_LEFT
// #define MASTER_RIGHT
// #define EE_HANDS

/* Select rows configuration */
// Rows are 4 or 5

/* key matrix size */
// Rows are doubled-up
#define MATRIX_ROWS 10
#define MATRIX_ROW_PINS { D4, C6, D7, E6, B4 }

// wiring of each half
#define MATRIX_COLS 8
#define MATRIX_COL_PINS { F4, F5, F6, F7, B1, B3, B2, B6 }
// #define MATRIX_COL_PINS { B2, B3, B1, F7, F6, F5, F4 } //uncomment this line and comment line above if you need to reverse left-to-right key order

/* define if matrix has ghost */
//#define MATRIX_HAS_GHOST

/* number of backlight levels */
// #define BACKLIGHT_LEVELS 3

/* Set 0 if debouncing isn't needed */
#define DEBOUNCING_DELAY 5

/* Mechanical locking support. Use KC_LCAP, KC_LNUM or KC_LSCR instead in keymap */
//#define LOCKING_SUPPORT_ENABLE
/* Locking resynchronize hack */
//#define LOCKING_RESYNC_ENABLE

/* key combination for command */
#define IS_COMMAND() ( \
    keyboard_report->mods == (MOD_BIT(KC_LSHIFT) | MOD_BIT(KC_RSHIFT)) \
)

/* ws2812 RGB LED */
#define RGB_DI_PIN D3
#define RGBLIGHT_TIMER
//#define RGBLED_NUM 12    // Number of LEDs. see ./keymaps/default/config.h
#define ws2812_PORTREG  PORTD
#define ws2812_DDRREG   DDRD

//#define RGBLIGHT_ANIMATIONS : see ./rules.mk: LED_ANIMATIONS = yes or no
//    see ./rules.mk: LED_BACK_ENABLE or LED_UNDERGLOW_ENABLE set yes
#ifdef RGBLED_BACK
  #define RGBLED_NUM 35
#else
  #define RGBLED_NUM 6
#endif

#ifndef IOS_DEVICE_ENABLE
  #if RGBLED_NUM <= 6
    #define RGBLIGHT_LIMIT_VAL 255
  #else
      #define RGBLIGHT_LIMIT_VAL 120
    #endif
  #define RGBLIGHT_VAL_STEP 17
#else
  #if RGBLED_NUM <= 6
    #define RGBLIGHT_LIMIT_VAL 90
  #else
      #define RGBLIGHT_LIMIT_VAL 35
  #endif
  #define RGBLIGHT_VAL_STEP 4
#endif
#define RGBLIGHT_HUE_STEP 10
#define RGBLIGHT_SAT_STEP 17

#if defined(RGBLIGHT_ENABLE) && !defined(IOS_DEVICE_ENABLE)
// USB_MAX_POWER_CONSUMPTION value for BlackMasK60 keyboard
//  120  RGBoff, OLEDoff
//  120  OLED
//  330  RGB 6
//  300  RGB 32
//  310  OLED & RGB 32
  #define USB_MAX_POWER_CONSUMPTION 400
#else
  // fix iPhone and iPad power adapter issue
  // iOS device need lessthan 100
  #define USB_MAX_POWER_CONSUMPTION 100
#endif

/*
 * Feature disable options
 *  These options are also useful to firmware size reduction.
 */

/* disable debug print */
// #define NO_DEBUG

/* disable print */
// #define NO_PRINT

/* disable action features */
//#define NO_ACTION_LAYER
//#define NO_ACTION_TAPPING
//#define NO_ACTION_ONESHOT
//#define NO_ACTION_MACRO
//#define NO_ACTION_FUNCTION


#endif

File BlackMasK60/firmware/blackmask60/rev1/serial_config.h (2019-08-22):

#ifndef SOFT_SERIAL_CONFIG_H
#define SOFT_SERIAL_CONFIG_H

/* Soft Serial defines */
#define SERIAL_PIN_DDR DDRD
#define SERIAL_PIN_PORT PORTD
#define SERIAL_PIN_INPUT PIND
#define SERIAL_PIN_MASK _BV(PD2)
#define SERIAL_PIN_INTERRUPT INT2_vect

#define SERIAL_USE_MULTI_TRANSACTION

//// #error rev1 serial config

#endif /* SOFT_SERIAL_CONFIG_H */

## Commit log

2019-05-20 BlackMasK60のビルドガイド記述はじめ。
2019-05-20 本来はMeishiのビルドガイドでした。書き直し
2019-05-20 Blackmask60 マニュアル追加
2019-05-25 メモ書きレベルのビルドガイド
2019-05-25 トップ画像追加
2019-05-25 Firmwareに関して記載追加
2019-07-07 Shiroのビルドガイドを追加
2019-07-16 ファームウェア書き込み手順を記載
2019-08-22 ビルドガイドの不明箇所を明確化
2019-08-22 BlackMask60のFirmware追加する
2019-11-29 Kuro ビルドガイドとりあえず書いた
2019-11-29 内容修正
2019-12-04 ファームウェア公開
2020-12-30 RURA66組み立てマニュアルを掲載
2021-01-11 RURA66の画像リソース追加と文面修正
2021-01-11 Shiroのビルドガイド誤字修正
2021-01-13 拡張子変更
2021-01-13 ビルドガイド修正
2021-01-13 KeyMap画像を差し替え
2021-06-04 マニュアルにお問い合わせ先を追記
2022-08-09 Shiro PCBを追加
    [logo_confirm.dxf, shiro.kicad_pcb, shiro.sch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]
2022-08-10 V6対応
    [shiro.kicad_sch]
2022-12-12 Readme.md修正とライセンス表記を追加
2022-12-12 ライセンス周り修正
2022-12-13 表記修正

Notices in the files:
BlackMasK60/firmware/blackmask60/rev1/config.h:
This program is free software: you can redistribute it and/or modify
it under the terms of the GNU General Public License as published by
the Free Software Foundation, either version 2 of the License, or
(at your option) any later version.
